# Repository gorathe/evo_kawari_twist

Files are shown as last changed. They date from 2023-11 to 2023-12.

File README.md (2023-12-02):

# evo_kawari_twist
PCB to rotate a Kawari large board to make the mini HDMI port more accessible. Intended for use with the EVO64.

This board rotates your VIC-II Kawari large board through 90º such that the mini-HDMI connector is more accessible to the left of the Kawari rather than to the back.
It's a four-layer PCB, and most of the copper is ground planes to try to shield the composite video LUMA and CHROMA signals from the fast-switching digital signals - rmr and auro have both expended a lot of effort to keep the video as clean as possible. I don't want to undo all that by running the video signals alongside the clocks.

This was knocked together very quickly, and so has some shortcomings:
- If your VIC-II position is populated with a ZIF socket, it will be tough, or impossible, to install this board directly into the ZIF socket. The workaround is to put a regular socket in the ZIF socket, latch that in place, and then install the Kawari Twist.
- The mounting hole (intended for use with a shortened M3 nylon standoff) isn't in the best position.
- There is a clearance problem inside a C64 breadbin case - I ended up soldering the Kawari directly to the PCB rather than using a socket. If you don't have a ZIF socket, then you'll have more clearance and won't have to take this rather drastic step.

COPYRIGHT: There is no copyright. Knock yourselves out.

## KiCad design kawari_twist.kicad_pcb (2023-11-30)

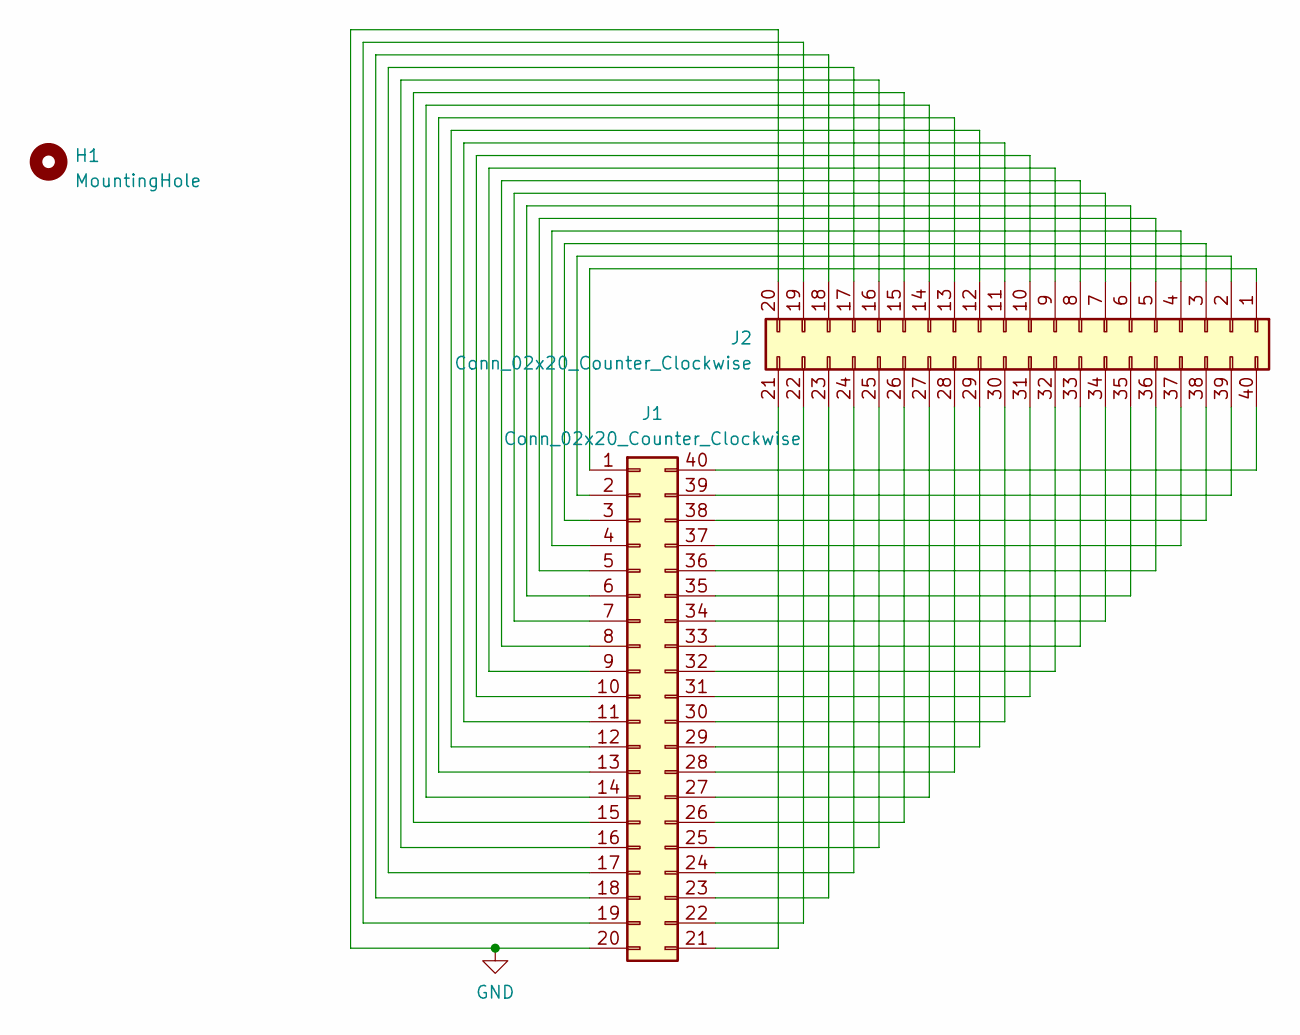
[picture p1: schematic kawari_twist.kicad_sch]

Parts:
H1: MountingHole; MountingHole_3.2mm_M3
J1, J2: Conn_02x20_Counter_Clockwise; DIP-40_W15.24mm

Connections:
GND: J1.20, J2.20
unnamed: J1.1, J2.1
unnamed: J1.2, J2.2
unnamed: J1.3, J2.3
unnamed: J1.4, J2.4
unnamed: J1.5, J2.5
unnamed: J1.6, J2.6
unnamed: J1.7, J2.7
unnamed: J1.8, J2.8
unnamed: J1.9, J2.9
unnamed: J1.10, J2.10
unnamed: J1.11, J2.11
unnamed: J1.12, J2.12
unnamed: J1.13, J2.13
unnamed: J1.14, J2.14
unnamed: J1.15, J2.15
unnamed: J1.16, J2.16
unnamed: J1.17, J2.17
unnamed: J1.18, J2.18
unnamed: J1.19, J2.19
unnamed: J1.21, J2.21
unnamed: J1.22, J2.22
unnamed: J1.23, J2.23
unnamed: J1.24, J2.24
unnamed: J1.25, J2.25
unnamed: J1.26, J2.26
unnamed: J1.27, J2.27
unnamed: J1.28, J2.28
unnamed: J1.29, J2.29
unnamed: J1.30, J2.30
unnamed: J1.31, J2.31
unnamed: J1.32, J2.32
unnamed: J1.33, J2.33
unnamed: J1.34, J2.34
unnamed: J1.35, J2.35
unnamed: J1.36, J2.36
unnamed: J1.37, J2.37
unnamed: J1.38, J2.38
unnamed: J1.39, J2.39
unnamed: J1.40, J2.40

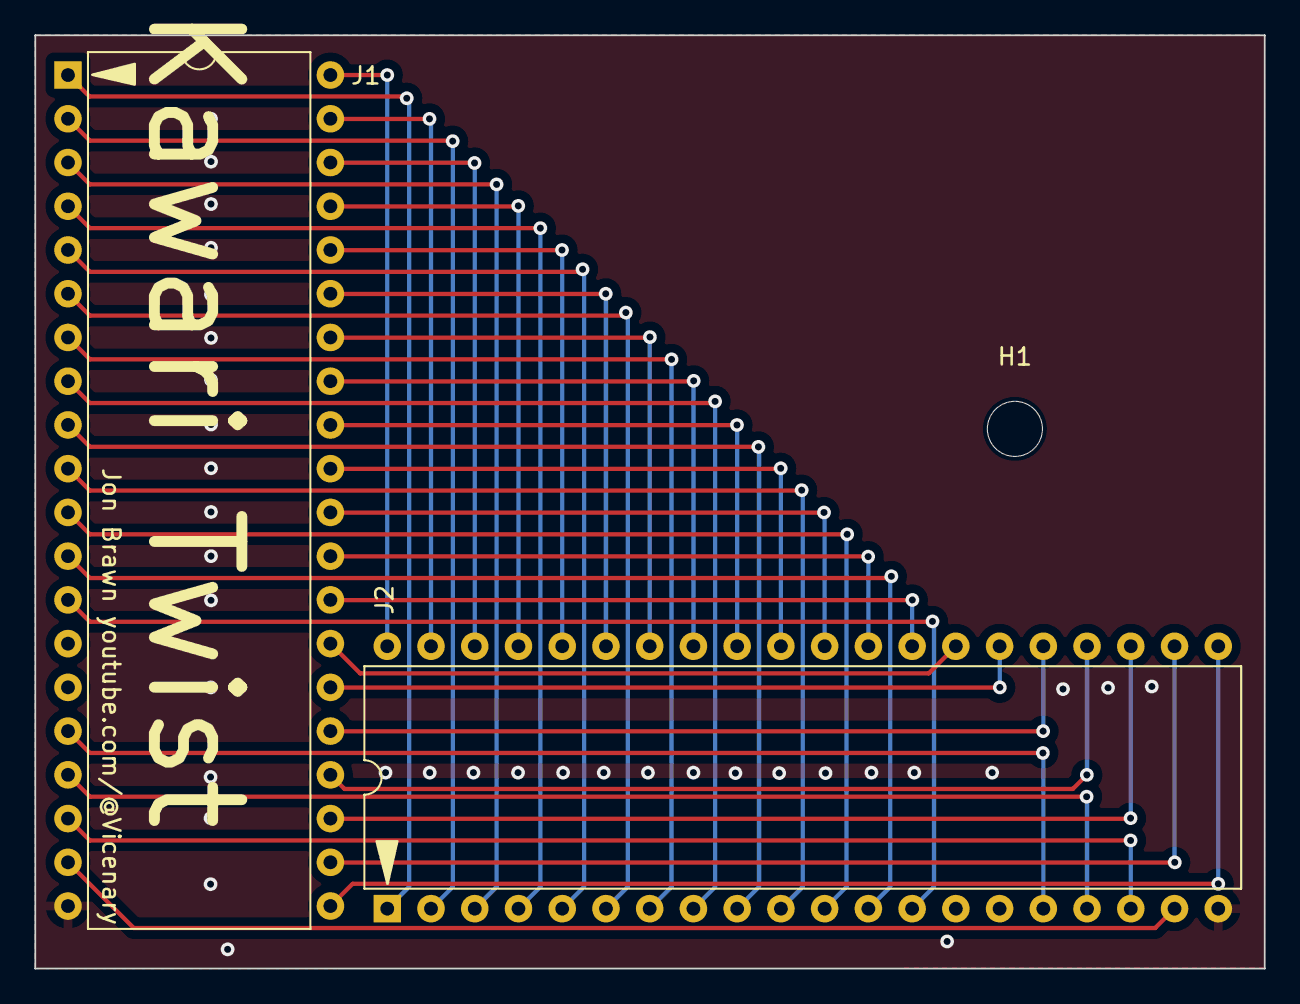
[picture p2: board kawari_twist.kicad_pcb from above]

Board: 4 copper layers, 71.4 x 54.2 mm, 3 parts (0 on the bottom side), 40 nets.

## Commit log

2023-11-30 Initial import
    [kawari_twister-B_Cu.gbl, kawari_twister-B_Mask.gbs, kawari_twister-B_Paste.gbp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]
2023-11-30 Rename to kawari_twist
    [kawari_twist-B_Cu.gbl, kawari_twist-B_Mask.gbs, kawari_twist-B_Paste.gbp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]
